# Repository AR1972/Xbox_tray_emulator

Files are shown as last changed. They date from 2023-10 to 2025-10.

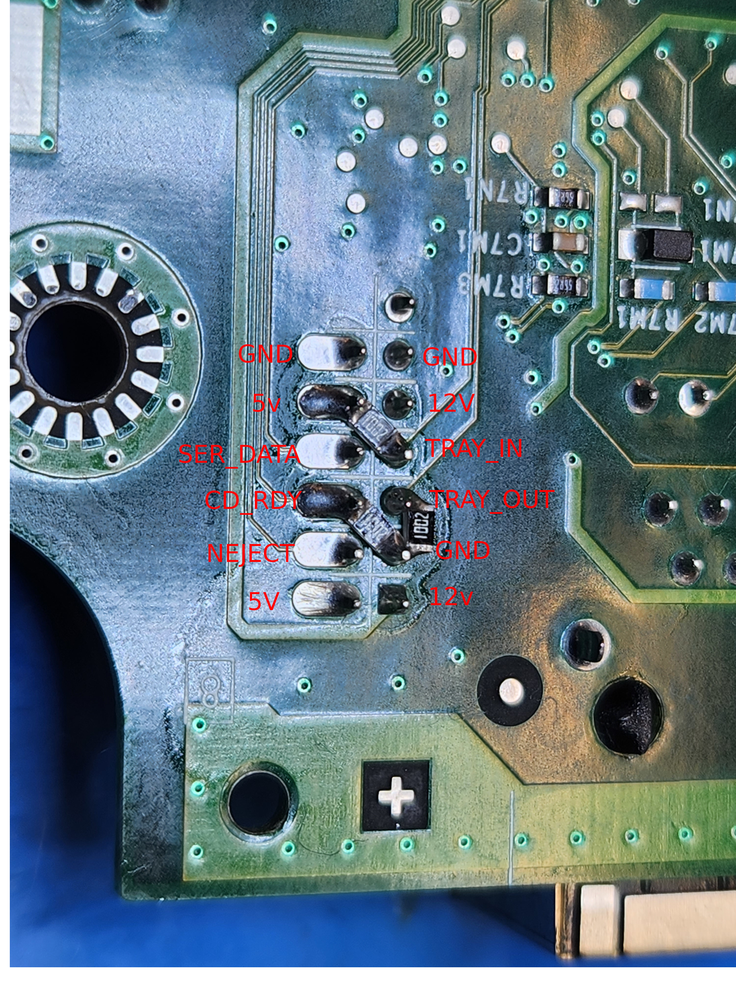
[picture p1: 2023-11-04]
media/20231024_164613.jpg

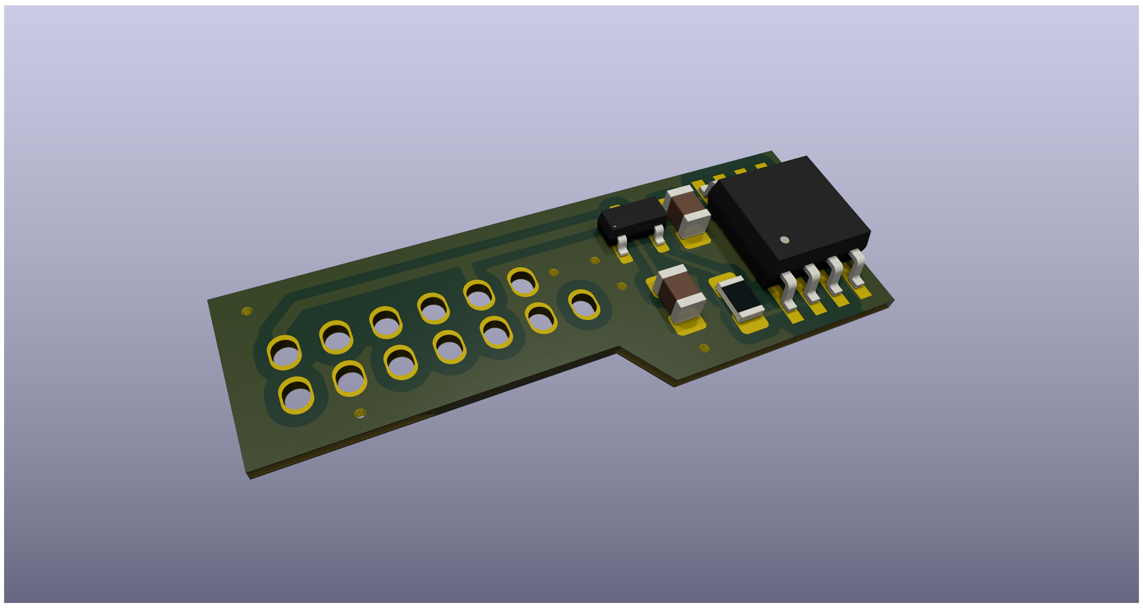
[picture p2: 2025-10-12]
PCB/QSB 1.6/xbox_tray_emulator_top.png

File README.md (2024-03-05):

# Original Xbox DVD tray emulator

# BOM
C1,C2 - 1uf 10v - 805

J1 - Hirose_DF11-14DP-2DSA not used for QSB

R1 - 10k - 805

U1 - ATTINY13A-SF or narrow ATTINY13A-SS7R - SOIC-8

U2 - AP2127N-3.3 - SOT-23

# PCB ordering info

Layers: 2

Thickness: 1.2mm

Material: FR-4: TG150

Min track/spacing: 6/6mil

Min hole size: 0.3mm

Surface finish: HASL with lead

Via process: Tenting vias

Finished copper: 1 oz Cu

# QSB ordering info

Layers: 2

Thickness: 0.6mm

Material: FR-4: TG150

Min track/spacing: 6/6mil

Min hole size: 0.3mm

Surface finish: HASL with lead

Via process: Tenting vias

Finished copper: 1 oz Cu

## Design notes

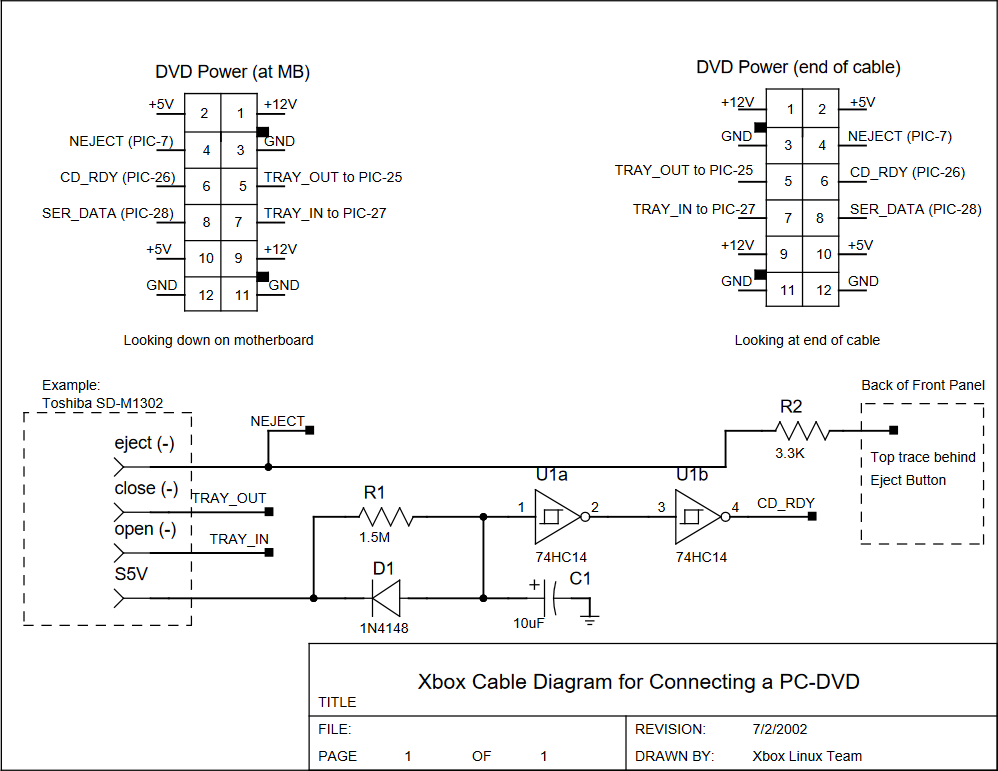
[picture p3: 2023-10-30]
datasheets/DVD_pinout.png

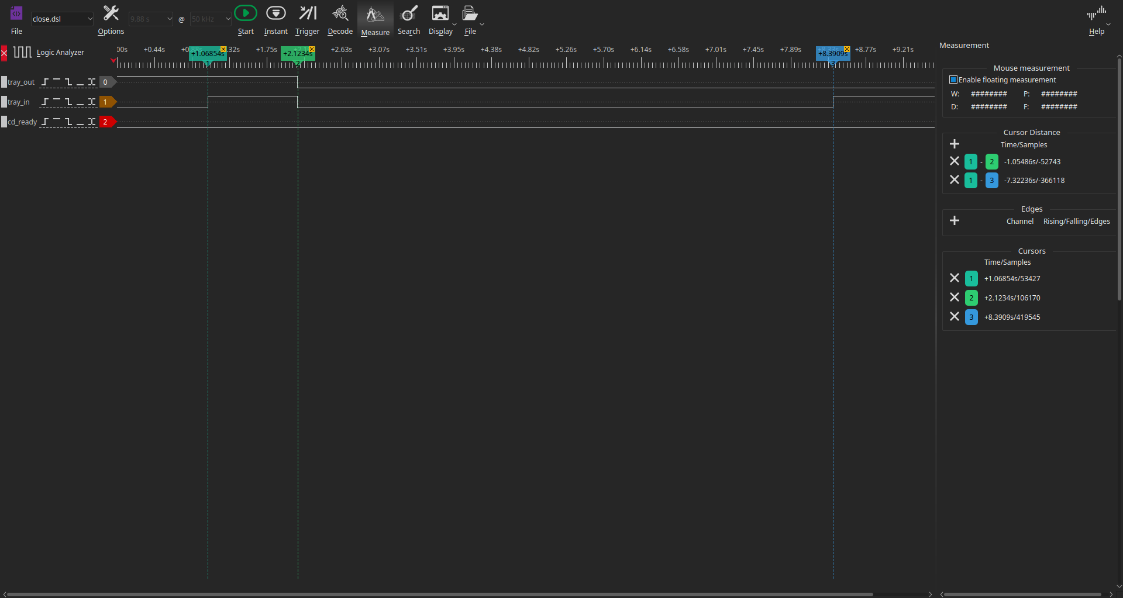
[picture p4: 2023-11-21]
media/DSView-231120-205317.png

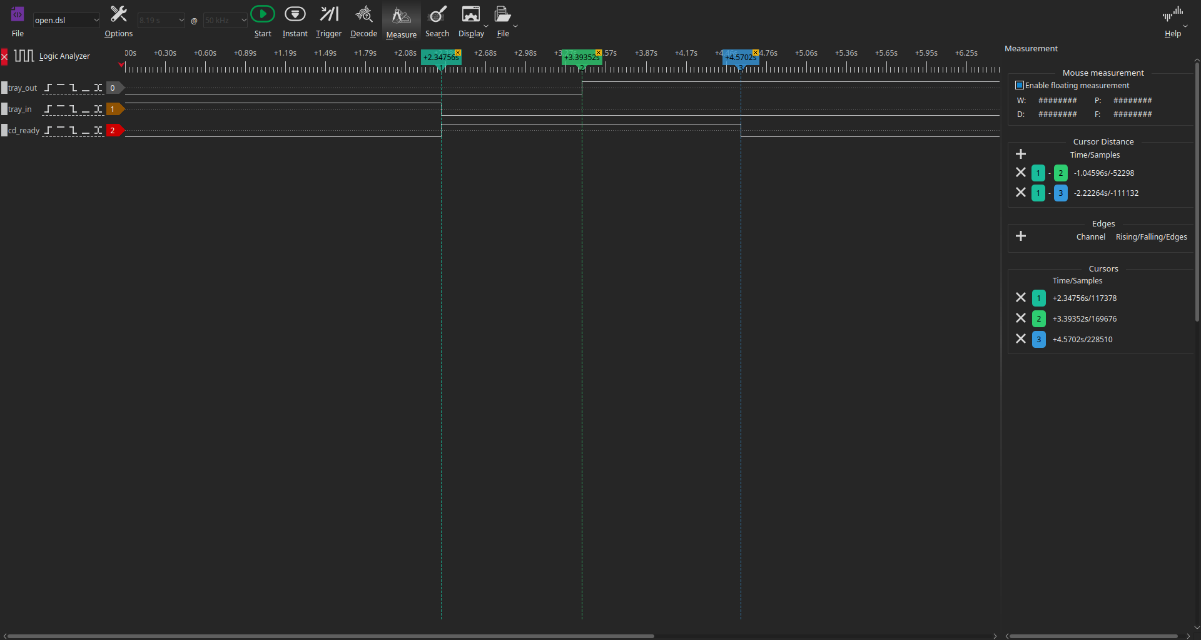
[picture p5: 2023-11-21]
media/DSView-231120-204927.png

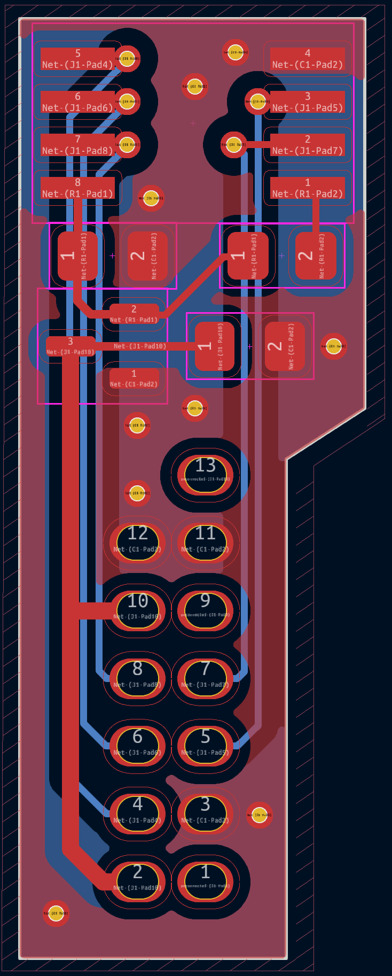
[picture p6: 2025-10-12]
PCB/QSB 1.6/Untitled.png

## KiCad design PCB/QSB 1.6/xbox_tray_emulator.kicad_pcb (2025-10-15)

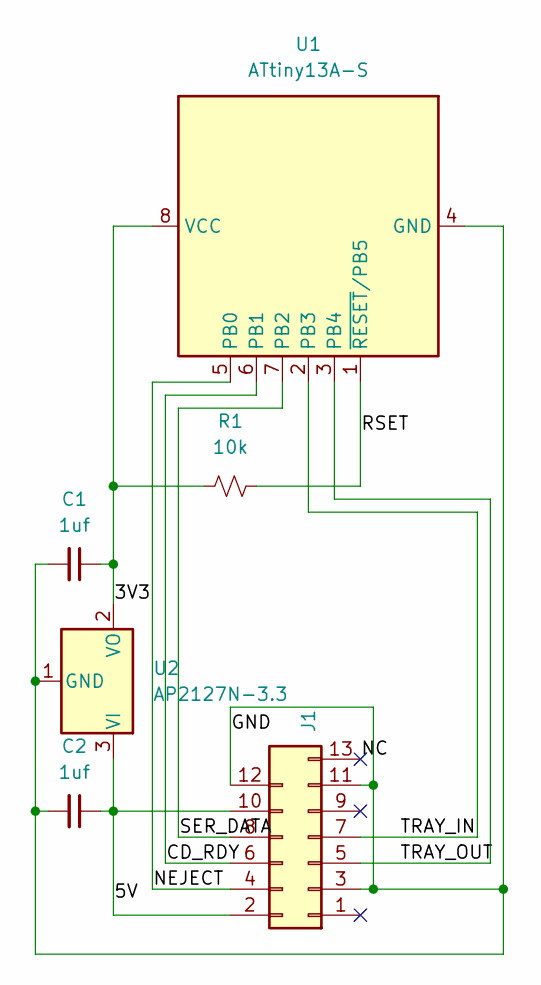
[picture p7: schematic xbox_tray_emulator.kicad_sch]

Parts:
C1, C2: 1uf; C_0805_2012Metric_Pad1.18x1.45mm_HandSolder
J1: to Xbox; Hirose_DF11-14DP-2DSA_2x07_P2.00mm_Vertical
R1: 10k; R_0805_2012Metric_Pad1.20x1.40mm_HandSolder
U1: ATtiny13A-S; SOIC-8W_5.3x5.3mm_P1.27mm
U2: AP2127N-3.3; SOT-23

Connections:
/3V3: C1.1, R1.1, U1.8 (VCC), U2.2 (VO)
/5V: C2.1, J1.2, J1.10, U2.3 (VI)
/CD_RDY: J1.6, U1.6 (PB1)
/GND: C1.2, C2.2, J1.3, J1.11, J1.12, U1.4 (GND), U2.1 (GND)
/NC: J1.13
/NEJECT: J1.4, U1.5 (PB0)
/RSET: R1.2, U1.1 (~RESET/PB5)
/SER_DATA: J1.8, U1.7 (PB2)
/TRAY_IN: J1.7, U1.2 (PB3)
/TRAY_OUT: J1.5, U1.3 (PB4)

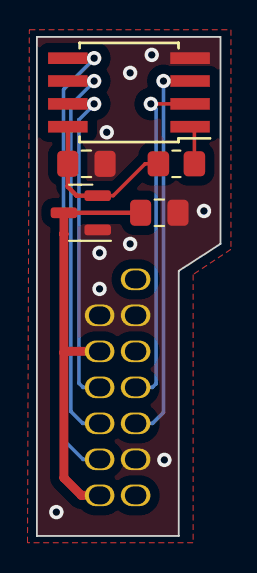
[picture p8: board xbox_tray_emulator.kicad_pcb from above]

Board: 2 copper layers, 10.2 x 27.7 mm, 6 parts (1 on the bottom side), 9 nets.

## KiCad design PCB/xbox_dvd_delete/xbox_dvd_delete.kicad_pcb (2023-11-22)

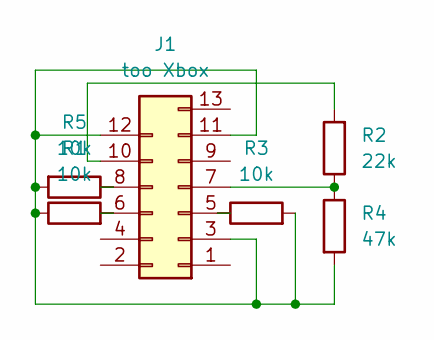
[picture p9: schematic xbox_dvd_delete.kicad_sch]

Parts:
J1: too Xbox; Hirose_DF11-14DP-2DSA_2x07_P2.00mm_Vertical
R1, R3, R5: 10k; R_0603_1608Metric_Pad0.98x0.95mm_HandSolder
R2: 22k; R_0603_1608Metric_Pad0.98x0.95mm_HandSolder
R4: 47k; R_0603_1608Metric_Pad0.98x0.95mm_HandSolder

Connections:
unnamed: J1.5, R3.1
unnamed: J1.6, R1.2
unnamed: J1.7, R2.1, R4.1
unnamed: J1.8, R5.1
unnamed: J1.10, R2.2
unnamed: J1.3, J1.11, J1.12, R1.1, R3.2, R4.2, R5.2

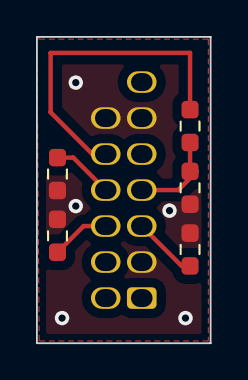
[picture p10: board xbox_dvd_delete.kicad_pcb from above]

Board: 2 copper layers, 9.7 x 17.0 mm, 6 parts (1 on the bottom side), 6 nets.

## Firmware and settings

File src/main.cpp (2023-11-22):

/*
	   DO WHAT THE FUCK YOU WANT TO PUBLIC LICENSE
					Version 2, December 2004

 Copyright (C) 2004 Sam Hocevar <sam@hocevar.net>

 Everyone is permitted to copy and distribute verbatim or modified
 copies of this license document, and changing it is allowed as long
 as the name is changed.

			DO WHAT THE FUCK YOU WANT TO PUBLIC LICENSE
   TERMS AND CONDITIONS FOR COPYING, DISTRIBUTION AND MODIFICATION

  0. You just DO WHAT THE FUCK YOU WANT TO.
*/

#include <Arduino.h>
#include <avr/sleep.h>
#include <avr/interrupt.h>
#include <avr/power.h>

#define CLOSED 1
#define OPEN 0
#define NEJECT_PIN PB0
#define CD_RDY_PIN PB1
#define SER_DATA_PIN PB2
#define TRAY_IN_PIN PB3
#define TRAY_OUT_PIN PB4

volatile bool tray_status = CLOSED;

void setup()
{
	// disable intrrupts
	cli();
	// ADC off
	ADCSRA &= ~_BV(ADEN);
	// setup pin 5 as our interrupt pin
	GIMSK |= _BV(PCIE);
	PCMSK |= _BV(NEJECT_PIN);
	pinMode(NEJECT_PIN, INPUT);
	// setup output
	pinMode(TRAY_OUT_PIN, OUTPUT);
	pinMode(TRAY_IN_PIN, OUTPUT);
	pinMode(SER_DATA_PIN, OUTPUT);
	pinMode(CD_RDY_PIN, OUTPUT);
	// setup as tray closed no disc in drive
	digitalWrite(TRAY_OUT_PIN, LOW);
	digitalWrite(TRAY_IN_PIN, HIGH);
	digitalWrite(CD_RDY_PIN, LOW);
	// terminate SER_DATA to avoid possible issues
	digitalWrite(SER_DATA_PIN, LOW);
	// enable interrupts
	sei();
}

void sleep()
{
	ACSR = ADMUX = ADCSRA = 0;
	// Analog comparator off
	ACSR |= _BV(ACD);
	// switch Analog to Digitalconverter off
	ADCSRA &= ~_BV(ADEN);
	set_sleep_mode(SLEEP_MODE_PWR_DOWN);
	power_all_disable();
	sleep_enable();
	cli();
	// Disable BOD, step 1
	BODCR = _BV(BODSE) | _BV(BODS);
	// Second step
	BODCR = _BV(BODS);
	sei();
	sleep_cpu();
	sleep_disable();
	power_all_enable();
}

ISR(PCINT0_vect)
{
	GIMSK &= ~_BV(PCIE);
	// NEJECT pin is normaly high only respond when pin changes to low
	if (!digitalRead(NEJECT_PIN))
	{
		if (tray_status == CLOSED)
		{
			// if tray is closed emulate the tray opening
			digitalWrite(CD_RDY_PIN, HIGH);
			digitalWrite(TRAY_IN_PIN, LOW);
			delay(1000);
			digitalWrite(TRAY_OUT_PIN, HIGH);
			delay(1000);
			digitalWrite(CD_RDY_PIN, LOW);
			tray_status = OPEN;
		}
		else
		{
			// if tray is open emulate the tray closing
			digitalWrite(CD_RDY_PIN, LOW);
			digitalWrite(TRAY_IN_PIN, HIGH);
			delay(1000);
			digitalWrite(TRAY_OUT_PIN, LOW);
			digitalWrite(TRAY_IN_PIN, LOW);
			delay(2000);
			digitalWrite(TRAY_IN_PIN, HIGH);
			tray_status = CLOSED;
		}
	}
	GIMSK |= _BV(PCIE);
}

void loop()
{
	// power down the cpu when not servicing an interrupt
	sleep();
}

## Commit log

2023-11-04 modify for ATtiny13A
    [xbox_tray_emulator.kicad_pcb, xbox_tray_emulator.kicad_sch]
2023-11-04 upload firmwar to socketed ATtiny13a via USBTINY
2023-11-04 set CPU frequency, correct delay
    [xbox_tray_emulator.kicad_pcb]
2023-11-05 add PCB
    [xbox_tray_emulator-B_Cu.gbr, xbox_tray_emulator-B_Mask.gbr, xbox_tray_emulator-Edge_Cuts.gbr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]
2023-11-05 PCB cleanup
    [xbox_tray_emulator-B_Cu.gbr, xbox_tray_emulator-B_Mask.gbr, xbox_tray_emulator-Edge_Cuts.gbr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]
2023-11-06 rename PCB directory, turn off ADC
    [xbox_tray_emulator.kicad_pcb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]
2023-11-06 reduce sleep current from 200uA to 50uA
    [xbox_tray_emulator.kicad_pcb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]
2023-11-07 Xbox DVD logic levels are 3.3v, a 3.3v regulator was added to the PCB so the ATtiny13a will output and accept 3.3v logic. ATtiny13a sleep current draw is now a fration of a uA. modify tray open seque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
    [xbox_tray_emulator.kicad_pcb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]
2023-11-09 add ground fill
    [xbox_tray_emulator.kicad_pcb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]
2023-11-12 add psudo-QSB
    [xbox_tray_emulator.kicad_pcb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]
2023-11-15 shrink PCB a little
    [xbox_tray_emulator.kicad_pcb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]
2023-11-21 correct pin signaling
2023-11-21 adjust pin timings, add logic analyzer images
2023-11-22 disable pin change interrupts while in ISR
2023-11-22 add passive dvd delete board
    [xbox_dvd_delete.kicad_pcb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]
2023-11-25 increase U1 pads for "narrow" ATtiny13
    [xbox_tray_emulator.kicad_pcb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]
2024-03-05 add BOM and PCB/QSB ordering info
2025-10-12 fix fitment for 1.6 revision Xbox
    [xbox_tray_emulator.kicad_pcb, xbox_tray_emulator.kicad_sch]
2025-10-15 add net lables, add firmware, update .gitignore
    [xbox_tray_emulator.kicad_pcb, xbox_tray_emulator.kicad_sch]
2025-10-15 adjust componets locations to make DRC happy, add gerbers.
    [xbox_tray_emulator.kicad_pcb, xbox_tray_emulator.kicad_sch]
